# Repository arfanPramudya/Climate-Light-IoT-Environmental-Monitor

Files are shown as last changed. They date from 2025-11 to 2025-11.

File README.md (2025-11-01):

# Climate Light: IoT Multi-Threat Monitoring & Safety System

**Climate Light** is an IoT project designed for real-time environmental monitoring and hazard detection. Built using the ESP8266 (NodeMCU) and the Blynk IoT platform, this system actively monitors temperature, humidity, flammable gas, and the presence of fire.

It provides a robust alerting system with both local alarms (a multi-priority buzzer, LED, and LCD screen) and remote notifications sent directly to your mobile device via the Blynk app. The system also features remote control capabilities, allowing you to toggle two AC devices (like lights or fans) from anywhere in the world.

]This project was developed by a team of Informatics Engineering students from the University of Lampung. 

## 🚀 Key Features

  * **Real-time Monitoring:** Tracks ambient temperature and humidity using a **DHT11** sensor.
  * **Gas Hazard Detection:** Senses flammable/harmful gas levels with an **MQ-2** sensor and triggers an alarm if the value exceeds a set threshold (300). 
  * **Flame Detection:** Uses a **Flame Sensor** to detect open flames for immediate fire alerts. 
  * **Remote Device Control:** Toggle two separate AC devices (e.g., 240V lamps) remotely using **Relay** switches controlled from the Blynk app (Virtual Pins V0, V1). 
  * **Prioritized Multi-Threat Alarm:** A smart alarm system with four distinct buzzer/LED patterns based on the detected threat level: 
      * **Level 1 (High Temp):** Slow Beep
      * **Level 2 (Gas Detected):** Medium Beep
      * **Level 3 (Flame Detected):** Fast Beep
      * **Level 4 (All Threats):** *Fastest Beep* (Fire, Gas, & High Temp simultaneously)
  * **Local LCD Display:** A 16x2 I2C LCD shows system status (WiFi/Blynk connection), cycles through sensor readings during normal operation, and displays specific warning messages during an alarm (e.g., "\!\!KEBAKARAN\!\!", "GAS BERBAHAYA"). 
  * **Instant Mobile Alerts:** Sends push notifications (Log Events) to the Blynk app for fire, gas, and high-temperature alerts, including the device's pre-defined location for context. 

## 📱 Blynk Dashboard

The Blynk dashboard provides a clean interface for monitoring all sensor data in real-time and accessing the remote control toggles.
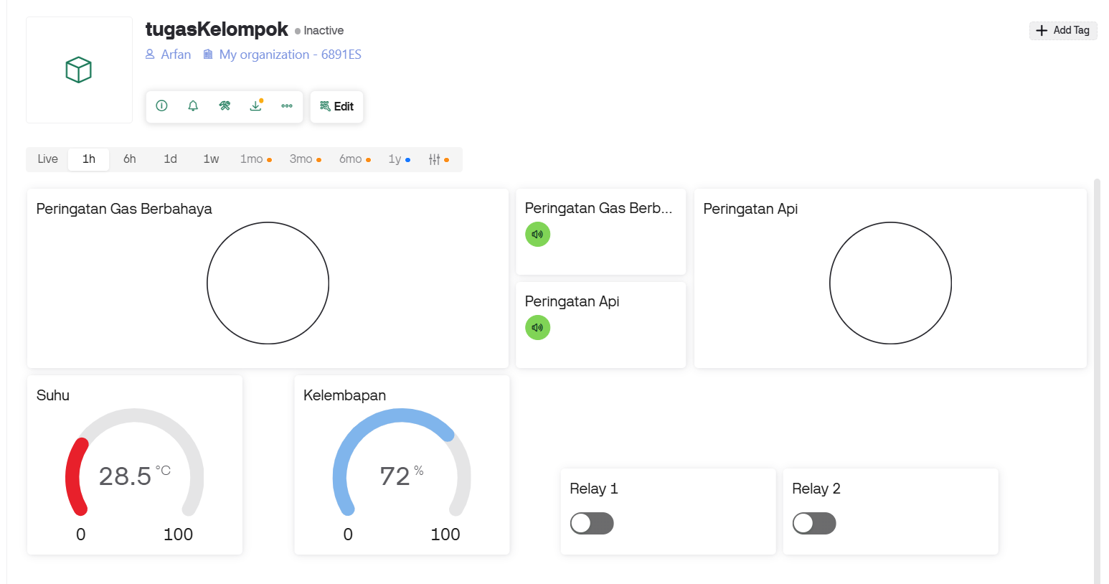
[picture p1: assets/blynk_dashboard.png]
Blynk Dashboard


## 🛠️ Hardware & Software

### Hardware Components

  * NodeMCU ESP8266
  * DHT11 (Temperature & Humidity Sensor)
  * MQ-2 (Gas Sensor Module)
  * Flame Sensor Module
  * 4-Channel Relay Module
  * Active Buzzer
  * 5mm LED (Red)
  * 1602 16x2 I2C LCD Display
  * Breadboard & Jumper Wires
  * (Opsional) AC Light Bulb, Socket, and external 240V AC power source for relay testing.

### Software, Services & Libraries

  * **Arduino IDE:** To compile and upload the firmware.
  * **Blynk IoT:** For the cloud backend, mobile dashboard, and notifications.
  * **Required Libraries:**
      * `BlynkSimpleEsp8266.h`
      * `ESP8266WiFi.h`
      * `DHT.h` (by Adafruit)
      * `Wire.h`
      * `LiquidCrystal_I2C.h` (by Frank de Brabander)

## 🔌 Wiring Diagram & Pinout

All components are connected to the NodeMCU ESP8266 as shown in the diagram and table below.
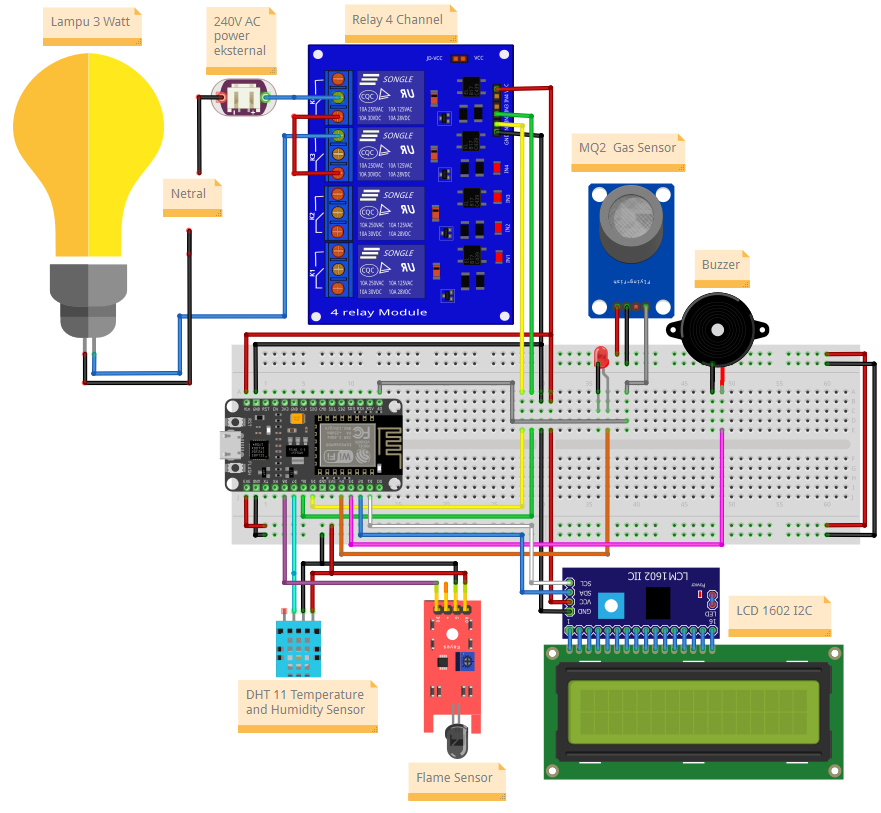
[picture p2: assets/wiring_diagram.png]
Wiring Diagram


### Pin Configuration

| Component | Pin on NodeMCU |
| :--- | :--- |
| **Buzzer** | `D3` |
| **LED** | `D4` |
| **DHT11 Sensor** (Data) | `D7` |
| **MQ-2 Sensor** (AOUT) | `A0` |
| **Flame Sensor** (DOUT) | `D8` |
| **Relay 1** (IN1) | `D5` |
| **Relay 2** (IN2) | `D6` |
| **LCD SDA** | `D2` |
| **LCD SCL** | `D1` |
| VCC (Sensors, LCD) | `3.3V` / `Vin` |
| GND | `GND` |

> ⚠️ **High Voltage Warning:** Connecting the relay module to an AC mains power source is extremely dangerous and carries a risk of electric shock, fire, or death. Always disconnect the AC power before making any adjustments. If you are not experienced, please seek help from a qualified professional.

## ⚙️ Setup & Installation Guide

Follow these steps to get your project up and running.

### 1\. Blynk App Setup

1.  **Create a New Template:** In the Blynk Web Dashboard or Mobile App, create a new template.
2.  **Get Credentials:** Your `BLYNK_TEMPLATE_ID`, `BLYNK_TEMPLATE_NAME`, and `BLYNK_AUTH_TOKEN` will be generated. You will need these for the firmware.
3.  **Configure Datastreams:** Go to the "Datastreams" tab and create the following virtual pins:

| Name | Virtual Pin | Data Type | Units | Min/Max |
| :--- | :--- | :--- | :--- | :--- |
| Relay 1 | `V0` | Integer | - | 0 / 1 |
| Relay 2 | `V1` | Integer | - | 0 / 1 |
| Suhu | `V2` | Double | °C | 0 / 100 |
| Kelembapan | `V3` | Integer | % | 0 / 100 |
| Gas Sensor | `V4` | Integer | ppm | 0 / 10000 |
| Peringatan Api | `V5` | Integer | - | 0 / 255 |
| deviceLocation | `V6` | String | - | - |

4.  **Design the Dashboard:** Drag and drop widgets onto your dashboard and assign them to the Datastreams you just created (e.g., Switch for V0/V1, Gauges for V2/V3, etc.).

### 2\. Firmware Setup

1.  **Clone the Repository:**

    ```bash
    git clone https://github.com/arfanPramudya/Climate-Light-IoT-Environmental-Monitor.git
    ```

2.  **Install Libraries:** Open the `.ino` file in the Arduino IDE. Go to **Sketch \> Include Library \> Manage Libraries...** and install the libraries listed in the "Software & Services" section above.

3.  **Update Credentials:** Open the `.ino` file and fill in your unique credentials at the top of the file:

    ```cpp
    // --- UPDATE THESE ---
    #define BLYNK_TEMPLATE_ID "Your Template ID"
    #define BLYNK_TEMPLATE_NAME "Your Template Name"
    #define BLYNK_AUTH_TOKEN "Your Auth Token From Blynk"

    char auth[] = BLYNK_AUTH_TOKEN;
    char ssid[] = "Your-WiFi-Name";
    char pass[] = "Your-WiFi-Password";
    // --- END UPDATE ---
    ```

### 3\. Upload the Code

1.  **Connect Your Board:** Plug your NodeMCU ESP8266 into your computer via USB.
2.  **Select Board:** In the Arduino IDE, go to **Tools \> Board** and select "NodeMCU 1.0 (ESP-12E Module)".
3.  **Select Port:** Go to **Tools \> Port** and select the correct COM port.
4.  **Upload:** Click the "Upload" button (right arrow) and wait for the process to complete.
5.  **Run:** Once uploaded, the device will connect to your WiFi and Blynk. You can open the Serial Monitor (set to 115200 baud) to see status messages and sensor readings.

## 👨‍💻 Project Team

This project was created as an academic assignment by:

  * **Arfan Andika Pramudya** (2315061016) - Team Leader
  * **Dhito Aryo Trengginas** (2315061015) 
  * **Muhammad Farhan** (2315061083) 
  * **M. Valerian Irwansyah** (2315061027) 
  * **M. Aqsha Fadilah J** (2315061127) 

-----

## 📄 License

This project is licensed under the MIT License. See the `LICENSE` file for details.

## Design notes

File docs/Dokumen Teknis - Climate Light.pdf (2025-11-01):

Dokumen Teknis : Climate Light

Tim Proyek :
Arfan Andika Pramudya | (2315061016) Team Leader
Dhito Aryo Trengginas | (2315061015)
Muhammad Farhan | (2315061083)
M. Valerian Irwansyah | (2315061027)
M. Aqsha Fadilah J | (2315061127)

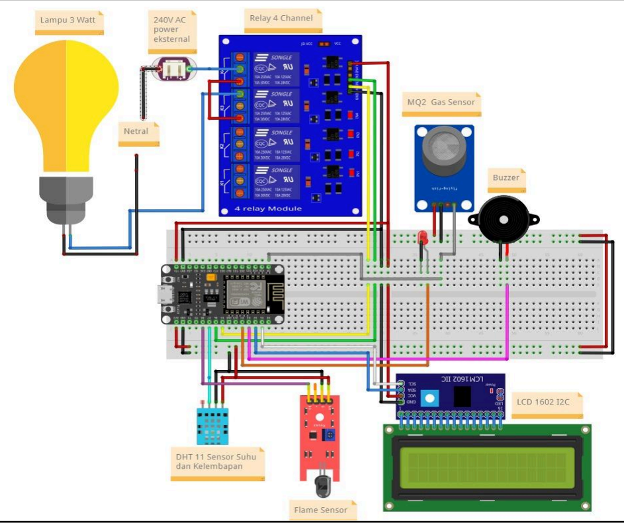
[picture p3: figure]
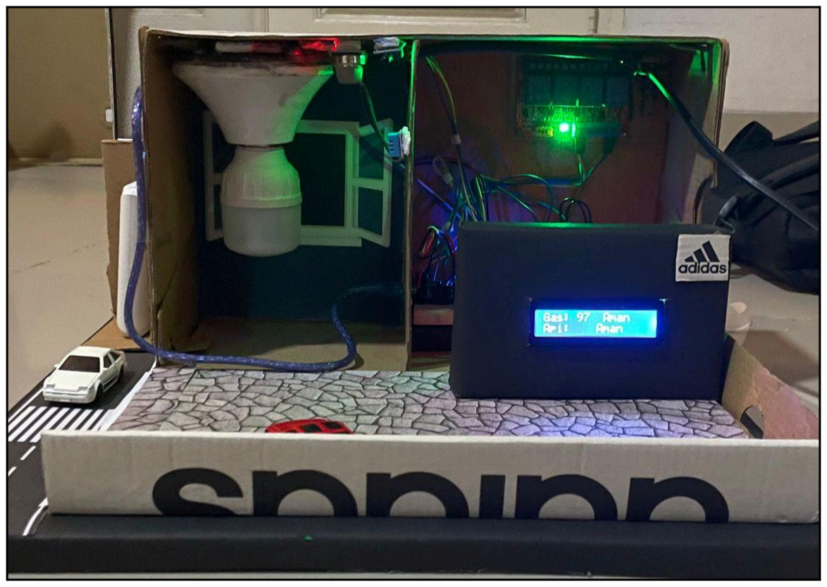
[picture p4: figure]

No. | Fitur | Penjelasan
1. | Monitoring suhu dan kelembaban | Ilustrasi: Ruangan dengan sistem pemantauan suhu dan kelembaban untuk mendeteksi kondisi lingkungan secara real-time. Jika suhu tinggi, alarm akan aktif dengan profil suara tertentu. Sensor: DHT11 Aktuator: Aplikasi Blynk, LED, Buzzer, LCD Tugas: 1. Mengecek suhu dan kelembaban udara. 2. Menampilkan suhu dan kelembaban ke aplikasi Blynk (V2, V3) dan LCD. 3. Jika tempHigh > (34.0°C), LED menyala dan buzzer berbunyi LAMBAT.
2. | Deteksi Gas | Ilustrasi: Sistem keamanan yang mendeteksi adanya kebocoran gas berbahaya di dalam ruangan. Jika terdeteksi, alarm akan aktif. Sensor: MQ-2 Aktuator: Aplikasi Blynk, LED, Buzzer, LCD Tugas: 1. Mengecek kadar gas (gasValue). 2. Menampilkan nilai gas ke aplikasi Blynk (V4) dan LCD. 3. Jika gasDetected > 300, LED menyala dan buzzer berbunyi SEDANG.
3. | Deteksi Api | Ilustrasi: Sistem keamanan yang mendeteksi adanya sumber api atau nyala api di dalam ruangan. Jika terdeteksi, alarm akan aktif. Sensor: Flame Sensor Aktuator: Aplikasi Blynk, LED, Buzzer, LCD Tugas: 1. Mengecek keberadaan api. 2. Menampilkan status api ke aplikasi Blynk (V5) dan LCD. 3. Jika flameDetected, LED menyala dan buzzer berbunyi dengan CEPAT.

4. | Integrasi Alarm Multi-Ancaman | Ilustrasi: Menggabungkan deteksi dari berbagai sensor untuk memberikan prioritas peringatan darurat tertinggi. Sensor: DHT11, MQ-2, Flame Sensor Aktuator: Aplikasi Blynk, LED, Buzzer, LCD Tugas: 1. Jika api, gas, dan suhu tinggi terdeteksi secara bersamaan, LED menyala dan buzzer berbunyi PALING CEPAT. 2. Mengirim notifikasi ke Blynk (EVENT_FIRE_ALERT).
5. | Kontrol lampu Jarak Jauh (Relay) | Ilustrasi: Pengguna dapat menyalakan atau mematikan lampu melalui aplikasi Blynk. Sensor: -Aktuator: Aplikasi Blynk, Relay, Bohlam Tugas: 1. Menerima perintah dari aplikasi Blynk (V0 dan V1). 2. Mengontrol status (ON/OFF) dari RELAY1_PIN dan RELAY2_PIN berdasarkan perintah Blynk.
6. | Tampilan LCD | Ilustrasi: Menampilkan informasi sensor secara lokal pada layar LCD. Sensor: DHT11, MQ-2, Flame Sensor Aktuator: LCD Tugas: 1. Menampilkan status koneksi WiFi dan Blynk saat startup. 2. Menampilkan nilai suhu, kelembaban, nilai gas, dan status api secara bergantian saat sistem dalam kondisi normal. 3. Menampilkan pesan peringatan spesifik ("!!KEBAKARAN!!", "API TERDETEKSI", "GAS BERBAHAYA", "SUHU TINGGI") saat alarm aktif.

7. Notifikasi Blynk dan Lokasi Perangkat

Ilustrasi: Mengirimkan notifikasi ke aplikasi Blynk untuk berbagai jenis peringatan dan menampilkan lokasi perangkat.

Sensor: DHT11, MQ-2, Flame Sensor

Aktuator: Aplikasi Blynk

Tugas:
1. Mengirim lokasi perangkat ke Blynk (V6) saat startup.
2. Mengirim notifikasi (log event) ke Blynk untuk peringatan kebakaran, gas, dan suhu tinggi, disertakan dengan lokasi perangkat atau detail suhu.

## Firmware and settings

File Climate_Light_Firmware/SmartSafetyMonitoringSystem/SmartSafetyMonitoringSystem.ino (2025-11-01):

#define BLYNK_TEMPLATE_ID "Your Template ID"
#define BLYNK_TEMPLATE_NAME "Your Template Name"
#define BLYNK_AUTH_TOKEN "Your Auth Token From BLYNK"

#include <ESP8266WiFi.h>
#include <BlynkSimpleEsp8266.h>
#include <DHT.h>
#include <Wire.h>
#include <LiquidCrystal_I2C.h>

#define BUZZER_PIN      D3
#define LED_PIN         D4
#define DHT_PIN         D7
#define GAS_PIN         A0
#define FLAME_PIN       D8
#define RELAY1_PIN      D5
#define RELAY2_PIN      D6
#define LCD_SDA_PIN     D2
#define LCD_SCL_PIN     D1

#define DHT_TYPE DHT11
#define TEMP_THRESHOLD      34.0f 
#define HUMIDITY_THRESHOLD  75.0f
#define GAS_THRESHOLD       300

#define EVENT_FIRE_ALERT    "fire_alert"
#define EVENT_GAS_ALERT     "gas_alert"
#define EVENT_TEMP_ALERT    "temp_alert"

char auth[] = BLYNK_AUTH_TOKEN;
char ssid[] = "Your Wifi Name";
char pass[] = "Your Wifi Password";
String deviceLocation = "Ruang H17 Gedung H, Teknik Elektro Universitas Lampung.";

DHT dht(DHT_PIN, DHT_TYPE);
LiquidCrystal_I2C lcd(0x27, 16, 2);

// --- VARIABEL ALARM ---
bool isAlarmActive = false;
unsigned long lastAlarmActionTime = 0;
bool isBuzzerOn = false;
int currentBuzzerFreq = 0;
// Variabel durasi diubah dari const menjadi variabel biasa untuk diatur secara dinamis
unsigned long currentBeepOnTime = 500;  
unsigned long currentBeepOffTime = 1000; 

unsigned long lastSensorRead = 0;
const unsigned long sensorReadInterval = 2000;
int lcdScreenState = 0;

BLYNK_WRITE(V0) {
  digitalWrite(RELAY1_PIN, param.asInt());
}

BLYNK_WRITE(V1) {
  digitalWrite(RELAY2_PIN, param.asInt());
}

void setup() {
  Serial.begin(115200);
  pinMode(BUZZER_PIN, OUTPUT);
  pinMode(LED_PIN, OUTPUT);
  pinMode(FLAME_PIN, INPUT_PULLUP);
  pinMode(RELAY1_PIN, OUTPUT);
  pinMode(RELAY2_PIN, OUTPUT);
  digitalWrite(RELAY1_PIN, LOW);
  digitalWrite(RELAY2_PIN, LOW);

  Wire.begin(LCD_SDA_PIN, LCD_SCL_PIN);
  lcd.init();
  lcd.backlight();
  dht.begin();
  
  lcd.print("Connecting WiFi");
  WiFi.begin(ssid, pass);
  while (WiFi.status() != WL_CONNECTED) {
    delay(500);
    Serial.print(".");
  }
  
  lcd.clear();
  lcd.print("Connecting Blynk");
  Blynk.begin(auth, ssid, pass);
  Blynk.virtualWrite(V6, deviceLocation);

  lcd.clear();
  lcd.print("Sistem SIAP!");
  Serial.println("\nSistem SIAP! Memulai monitoring...");
  delay(1500);
}

void loop() {
  Blynk.run();  
  handleAlarmSystem(); 
  if (millis() - lastSensorRead >= sensorReadInterval) {
    lastSensorRead = millis();
    checkSensorsAndAlerts();
  }
}

// --- FUNGSI handleAlarmSystem ---
void handleAlarmSystem() {
  if (!isAlarmActive) {
    noTone(BUZZER_PIN);
    digitalWrite(LED_PIN, LOW);
    isBuzzerOn = false;
    return;
  }

  digitalWrite(LED_PIN, (millis() % 400) < 200);

  if (isBuzzerOn) {
    if (millis() - lastAlarmActionTime > currentBeepOnTime) { // variabel dinamis
      noTone(BUZZER_PIN);
      isBuzzerOn = false;
      lastAlarmActionTime = millis();
    }
  } else {
    if (millis() - lastAlarmActionTime > currentBeepOffTime) { // variabel dinamis
      tone(BUZZER_PIN, currentBuzzerFreq);
      isBuzzerOn = true;
      lastAlarmActionTime = millis();
    }
  }
}

// --- FUNGSI checkSensorsAndAlerts ---
void checkSensorsAndAlerts() {
  float temp = dht.readTemperature();
  float hum = dht.readHumidity();
  int gasValue = analogRead(GAS_PIN);

  bool flameDetected = (digitalRead(FLAME_PIN) == LOW);
  bool gasDetected = (gasValue > GAS_THRESHOLD);
  bool tempHigh = (temp > TEMP_THRESHOLD);

  if (isnan(temp) || isnan(hum)) {
    Serial.println("Gagal membaca dari sensor DHT!");
    return;
  }

  Blynk.virtualWrite(V2, temp);
  Blynk.virtualWrite(V3, hum);
  Blynk.virtualWrite(V4, gasValue);
  Blynk.virtualWrite(V5, flameDetected ? 255 : 0);

  if (flameDetected && gasDetected && tempHigh) {
    isAlarmActive = true;
    // --- Profil Suara: PALING CEPAT ---
    currentBuzzerFreq = 3000;
    currentBeepOnTime = 150;  
    currentBeepOffTime = 150;
    
    lcd.clear();
    lcd.setCursor(0,0);
    lcd.print("!!KEBAKARAN!!");
    lcd.setCursor(0,1);
    lcd.print("Api,Gas,Suhu UP");
    Blynk.logEvent(EVENT_FIRE_ALERT, "KEBAKARAN TERDETEKSI di " + deviceLocation);

  } else if (flameDetected) {
    isAlarmActive = true;
    // --- Profil Suara: CEPAT ---
    currentBuzzerFreq = 2500;
    currentBeepOnTime = 200; 
    currentBeepOffTime = 400;

    lcd.clear();
    lcd.setCursor(0,0);
    lcd.print("!!PERINGATAN!!");
    lcd.setCursor(0,1);
    lcd.print("API TERDETEKSI");
    
  } else if (gasDetected) {
    isAlarmActive = true;
    // --- Profil Suara: SEDANG ---
    currentBuzzerFreq = 1500;
    currentBeepOnTime = 300;
    currentBeepOffTime = 700;

    lcd.clear();
    lcd.setCursor(0,0);
    lcd.print("!!PERINGATAN!!");
    lcd.setCursor(0,1);
    lcd.print("GAS BERBAHAYA");
    Blynk.logEvent(EVENT_GAS_ALERT, "Gas berbahaya terdeteksi di " + deviceLocation);

  } else if (tempHigh) {
    isAlarmActive = true;
    // --- Profil Suara: PALING LAMBAT ---
    currentBuzzerFreq = 800;
    currentBeepOnTime = 500;
    currentBeepOffTime = 1500;

    lcd.clear();
    lcd.setCursor(0,0);
    lcd.print("!!PERINGATAN!!");
    lcd.setCursor(0,1);
    lcd.print("SUHU TINGGI: " + String(temp, 1) + "C");
    Blynk.logEvent(EVENT_TEMP_ALERT, "Suhu terlalu tinggi (" + String(temp, 1) + "C)");
    
  } else {
    if (isAlarmActive) {
      lcd.clear();
    }
    isAlarmActive = false;
    displayNormalStatus(temp, hum, gasValue, flameDetected);
  }
}

// FUNGSI displayNormalStatus
void displayNormalStatus(float temp, float hum, int gasValue, bool flame) {
  if (isAlarmActive) return;
  // Menggunakan metode padding spasi
  String line1, line2;

  if (lcdScreenState == 0) {
    line1 = "Suhu:   " + String(temp, 1) + "C";
    line2 = "Lembab: " + String(hum, 1) + "%";
    lcdScreenState = 1;
  } else {
    line1 = "Gas: " + String(gasValue);
    line2 = "Api:    " + String(flame ? "ADA" : "Aman");
    lcdScreenState = 0;
  }
  
  while(line1.length() < 16) line1 += " ";
  while(line2.length() < 16) line2 += " ";

  lcd.setCursor(0, 0);
  lcd.print(line1);
  lcd.setCursor(0, 1);
  lcd.print(line2);
  
  Serial.print("Suhu: " + String(temp, 1) + "C");
  Serial.print(" | Lembab: " + String(hum, 1) + "%");
  Serial.print(" | Gas: " + String(gasValue));
  Serial.print(" | Api: ");
  Serial.println(flame ? "ADA" : "Aman");
}

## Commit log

2025-11-01 Add docs files
    [Wiring Diagram Climate Light.fzz]
2025-11-01 Update README with images and repository link
    Updated repository link and added images for Blynk dashboard and wiring diagram.
